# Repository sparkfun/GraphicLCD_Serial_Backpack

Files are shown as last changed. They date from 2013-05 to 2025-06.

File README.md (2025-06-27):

Graphic LCD Serial Backpack
============================
[Graphic LCD Serial Backpack
*Graphic LCD Serial Backpack(LCD-09352)*](https://www.sparkfun.com/products/9352)

The Graphic LCD Serial Backpack interfaces to either the [160x128 pixel Huge Graphic LCD](https://www.sparkfun.com/products/8799) or
the [128x64 pixel display](https://www.sparkfun.com/products/710). The backpack will allow you to write text, draw lines, circles and boxes, 
set and reset individual pixels, and erase specific blocks of the display. 

Repository Contents
-------------------
* **/Firmware** - The firmware that comes installed on the backpack
* **/Hardware** - All Eagle design files (.brd, .sch)

Product Versions
----------------
* [LCD-09352](https://www.sparkfun.com/products/9352)- Graphic Serial LCD Backpack by itself
* [LCD-09351](https://www.sparkfun.com/products/9351) - Serial Graphic LCD 128x64 (LCD + backpack)
* [LCD-08884](https://www.sparkfun.com/products/8884) - Serial Graphic LCD 160x128 (LCD + backpack)

License Information
-------------------
The hardware is released under [Creative Commons Share-alike 3.0](http://creativecommons.org/licenses/by-sa/3.0/).  
All other code is open source so please feel free to do anything you want with it; you buy me a beer if you use this and we meet someday ([Beerware license](http://en.wikipedia.org/wiki/Beerware)).

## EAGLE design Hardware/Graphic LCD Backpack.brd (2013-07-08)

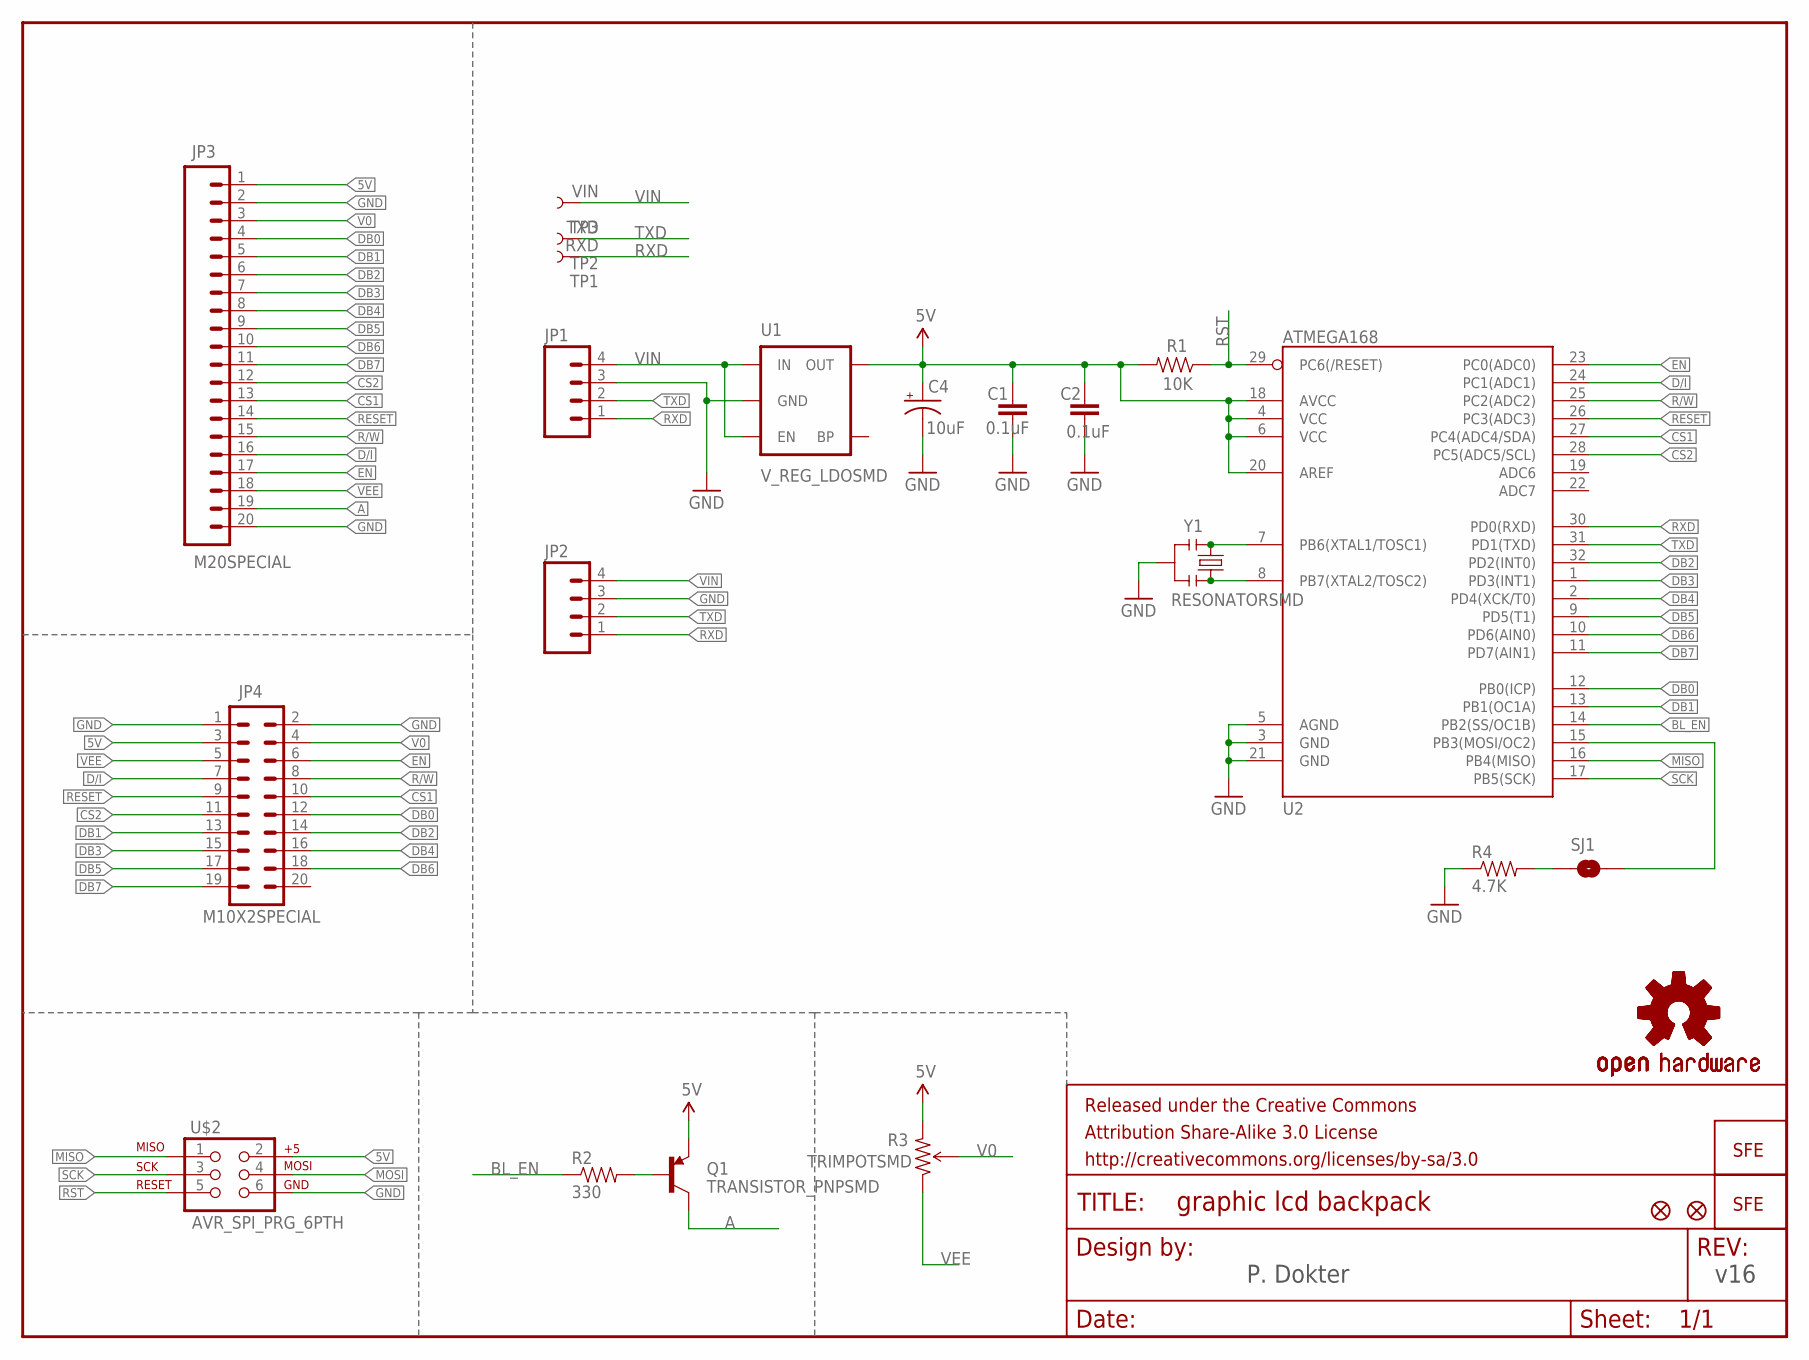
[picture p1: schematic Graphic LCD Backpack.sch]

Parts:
C1, C2: 0.1uF; 0603-CAP
C4: 10uF; EIA3216
FRAME1: FRAME-LETTER; CREATIVE_COMMONS
JP1: M04SMD; 1X04-SMD
JP2: M04PTH; 1X04
JP3: M20SPECIAL; 1X20_LOCK_SPECIAL
JP4: M10X2SPECIAL; 2X10_LOCK_SPECIAL
LOGO1: OSHW-LOGOL; OSHW-LOGO-L
LOGO2: LOGO-SFENEW; SFE-NEW-WEBLOGO
LOGO3: OSHW-LOGOS; OSHW-LOGO-S
Q1: TRANSISTOR_PNPSMD; SOT23-3
R1: 10K; 0603-RES
R2: 330; 0603-RES
R3: TRIMPOTSMD; TRIMPOT-3MM
R4: 4.7K; 0603-RES
SJ1: SOLDERJUMPERNC2; SJ_2S-NOTRACE
TP1: RXD; PAD.03X.05
TP2: TXD; PAD.03X.05
TP3: VIN; PAD.03X.05
U1: V_REG_LDOSMD; SOT23-5
U2: ATMEGA168; TQFP32-08
U$2: AVR_SPI_PRG_6PTH; 2X3
U$8: LOGO-SFENEW; SFE-NEW-WEBLOGO
U$9, U$10: FIDUCIAL1X2; FIDUCIAL-1X2
Y1: RESONATORSMD; RESONATOR-SMD

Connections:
5V: C1.1, C2.2, C4.A (+), JP3.1, JP4.3, Q1.2 (E), R1.2, R3.3 (CW), U1.5 (OUT), U2.4 (VCC), U2.6 (VCC), U2.18 (AVCC), U2.20 (AREF), U$2.2
A: JP3.19, Q1.3 (C)
BL_EN: R2.1, U2.14 (PB2(SS/OC1B))
CS1: JP3.13, JP4.10, U2.27 (PC4(ADC4/SDA))
CS2: JP3.12, JP4.11, U2.28 (PC5(ADC5/SCL))
D/I: JP3.16, JP4.7, U2.24 (PC1(ADC1))
DB0: JP3.4, JP4.12, U2.12 (PB0(ICP))
DB1: JP3.5, JP4.13, U2.13 (PB1(OC1A))
DB2: JP3.6, JP4.14, U2.32 (PD2(INT0))
DB3: JP3.7, JP4.15, U2.1 (PD3(INT1))
DB4: JP3.8, JP4.16, U2.2 (PD4(XCK/T0))
DB5: JP3.9, JP4.17, U2.9 (PD5(T1))
DB6: JP3.10, JP4.18, U2.10 (PD6(AIN0))
DB7: JP3.11, JP4.19, U2.11 (PD7(AIN1))
EN: JP3.17, JP4.6, U2.23 (PC0(ADC0))
GND: C1.2, C2.1, C4.C (-), JP1.3, JP2.3, JP3.2, JP3.20, JP4.1, JP4.2, R4.1, U1.2 (GND), U2.3 (GND), U2.5 (AGND), U2.21 (GND), U$2.6, Y1.2
MISO: U2.16 (PB4(MISO)), U$2.1
MOSI: SJ1.2, U2.15 (PB3(MOSI/OC2)), U$2.4
unnamed: Q1.1 (B), R2.2
unnamed: U2.7 (PB6(XTAL1/TOSC1)), Y1.1
unnamed: U2.8 (PB7(XTAL2/TOSC2)), Y1.3
unnamed: R4.2, SJ1.1
R/W: JP3.15, JP4.8, U2.25 (PC2(ADC2))
RESET: JP3.14, JP4.9, U2.26 (PC3(ADC3))
RST: R1.1, U2.29 (PC6(/RESET)), U$2.5
RXD: JP1.1, JP2.1, TP1.P$1, U2.30 (PD0(RXD))
SCK: U2.17 (PB5(SCK)), U$2.3
TXD: JP1.2, JP2.2, TP2.P$1, U2.31 (PD1(TXD))
V0: JP3.3, JP4.4, R3.2 (WIPER)
VEE: JP3.18, JP4.5, R3.1 (CCW)
VIN: JP1.4, JP2.4, TP3.P$1, U1.1 (IN), U1.3 (EN)

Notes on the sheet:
v16
P. Dokter

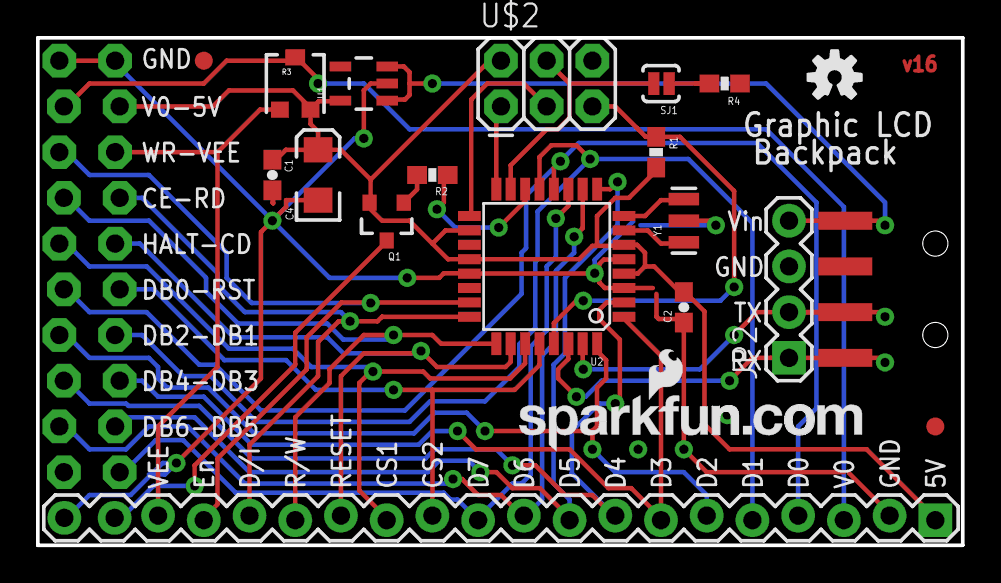
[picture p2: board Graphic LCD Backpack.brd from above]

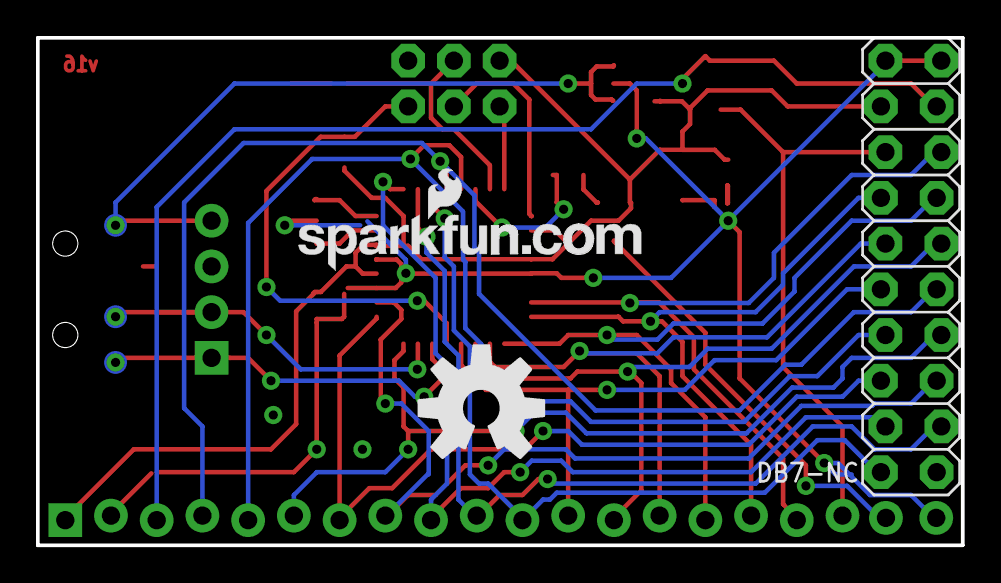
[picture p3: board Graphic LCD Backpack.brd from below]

Board: 2 copper layers, 51.4 x 28.2 mm, 27 parts (6 on the bottom side), 31 nets.

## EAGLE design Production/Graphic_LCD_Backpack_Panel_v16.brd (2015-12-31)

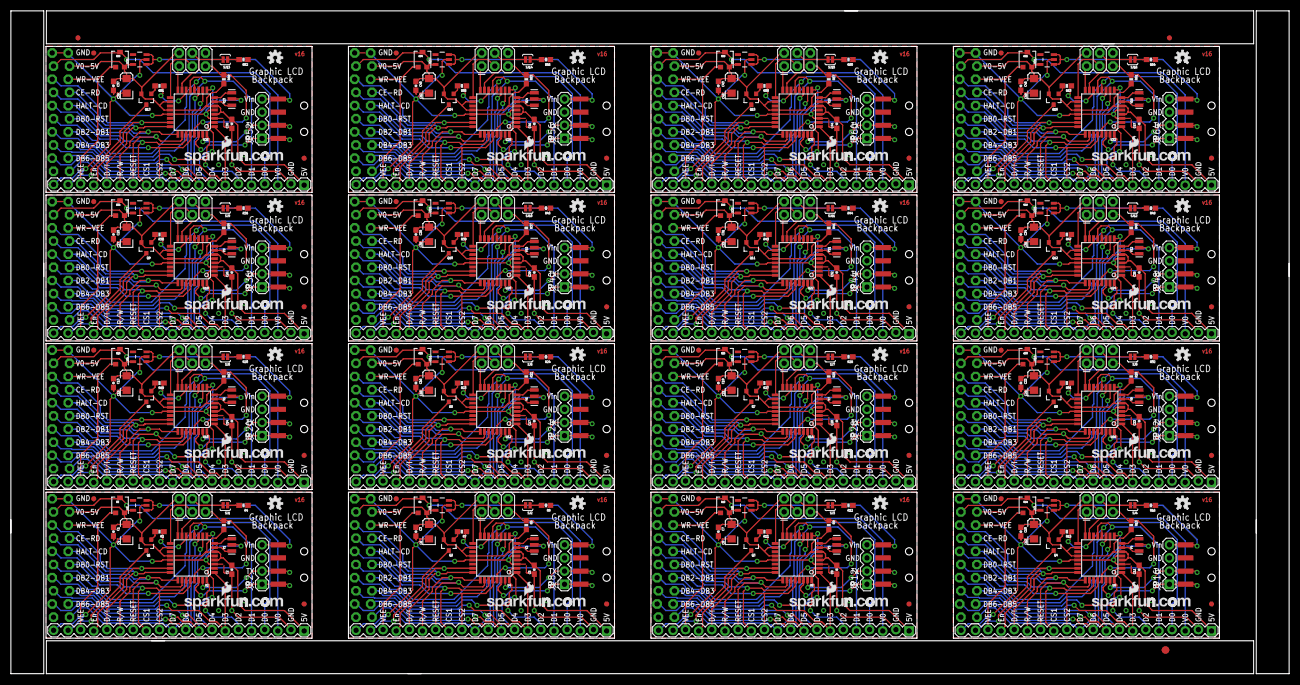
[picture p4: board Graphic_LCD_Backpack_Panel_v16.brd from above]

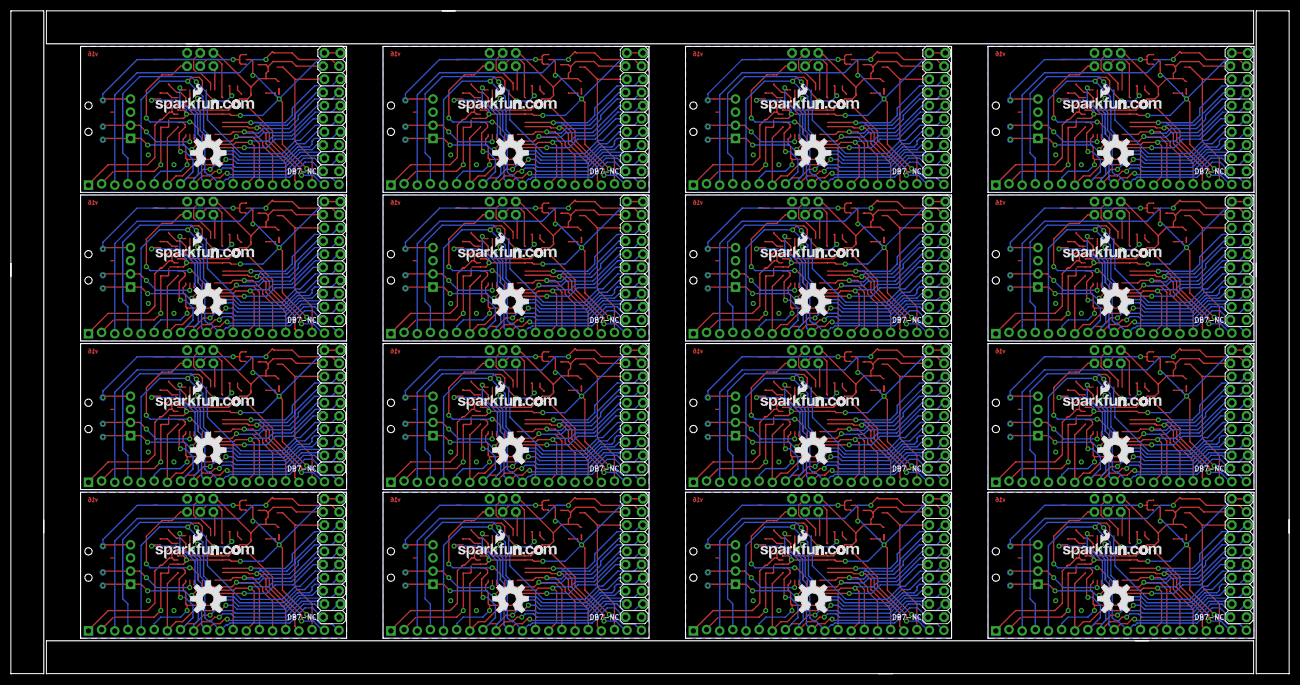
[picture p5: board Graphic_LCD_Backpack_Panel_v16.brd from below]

Board: 2 copper layers, 246.9 x 128.0 mm, 419 parts (96 on the bottom side), 496 nets.

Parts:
C1, C2, C3, C5, C7, C8, C10, C11, C13, C14, C16, C17, C19, C20, C22, C23, C25, C26, C28, C29, C31, C32, C34, C35, C37, C38, C40, C41, C43, C44, C46, C47: 0.1uF; 0603-CAP
C4, C6, C9, C12, C15, C18, C21, C24, C27, C30, C33, C36, C39, C42, C45, C48: 10uF; EIA3216
E$1: FIDUCIAL-1.5X3
E$7, E$8: FIDUCIAL-1X2
JP1, JP7, JP11, JP15, JP19, JP23, JP27, JP31, JP35, JP39, JP43, JP47, JP51, JP55, JP59, JP63: 1X04-SMD
JP2, JP8, JP12, JP16, JP20, JP24, JP28, JP32, JP36, JP40, JP44, JP48, JP52, JP56, JP60, JP64: 1X04
JP3, JP5, JP9, JP13, JP17, JP21, JP25, JP29, JP33, JP37, JP41, JP45, JP49, JP53, JP57, JP61: M20SPECIAL; 1X20_LOCK_SPECIAL
JP4, JP6, JP10, JP14, JP18, JP22, JP26, JP30, JP34, JP38, JP42, JP46, JP50, JP54, JP58, JP62: M10X2SPECIAL; 2X10_LOCK_SPECIAL
LOGO1, LOGO4, LOGO7, LOGO10, LOGO13, LOGO16, LOGO19, LOGO22, LOGO25, LOGO28, LOGO31, LOGO34, LOGO37, LOGO40, LOGO43, LOGO46: OSHW-LOGOL; OSHW-LOGO-L
LOGO2, LOGO5, LOGO8, LOGO11, LOGO14, LOGO17, LOGO20, LOGO23, LOGO26, LOGO29, LOGO32, LOGO35, LOGO38, LOGO41, LOGO44, LOGO47: LOGO-SFENEW; SFE-NEW-WEBLOGO
LOGO3, LOGO6, LOGO9, LOGO12, LOGO15, LOGO18, LOGO21, LOGO24, LOGO27, LOGO30, LOGO33, LOGO36, LOGO39, LOGO42, LOGO45, LOGO48: OSHW-LOGOS; OSHW-LOGO-S
Q1, Q2, Q3, Q4, Q5, Q6, Q7, Q8, Q9, Q10, Q11, Q12, Q13, Q14, Q15, Q16: TRANSISTOR_PNPSMD; SOT23-3
R1, R5, R9, R13, R17, R21, R25, R29, R33, R37, R41, R45, R49, R53, R57, R61: 10K; 0603-RES
R2, R7, R11, R15, R19, R23, R27, R31, R35, R39, R43, R47, R51, R55, R59, R63: 330; 0603-RES
R3, R6, R10, R14, R18, R22, R26, R30, R34, R38, R42, R46, R50, R54, R58, R62: TRIMPOTSMD; TRIMPOT-3MM
R4, R8, R12, R16, R20, R24, R28, R32, R36, R40, R44, R48, R52, R56, R60, R64: 4.7K; 0603-RES
SJ1, SJ2, SJ3, SJ4, SJ5, SJ6, SJ7, SJ8, SJ9, SJ10, SJ11, SJ12, SJ13, SJ14, SJ15, SJ16: SOLDERJUMPERNC2; SJ_2S-NOTRACE
TP1, TP4, TP7, TP10, TP13, TP16, TP19, TP22, TP25, TP28, TP31, TP34, TP37, TP40, TP43, TP46: RXD; PAD.03X.05
TP2, TP5, TP8, TP11, TP14, TP17, TP20, TP23, TP26, TP29, TP32, TP35, TP38, TP41, TP44, TP47: TXD; PAD.03X.05
TP3, TP6, TP9, TP12, TP15, TP18, TP21, TP24, TP27, TP30, TP33, TP36, TP39, TP42, TP45, TP48: VIN; PAD.03X.05
U1, U3, U5, U7, U9, U11, U13, U15, U17, U19, U21, U23, U25, U27, U29, U31: V_REG_LDOSMD; SOT23-5
U2, U4, U6, U8, U10, U12, U14, U16, U18, U20, U22, U24, U26, U28, U30, U32: ATMEGA168; TQFP32-08
U$1, U$6, U$8, U$13, U$17, U$21, U$25, U$29, U$33, U$37, U$41, U$45, U$49, U$53, U$57, U$61: LOGO-SFENEW; SFE-NEW-WEBLOGO
U$2, U$5, U$12, U$16, U$20, U$24, U$28, U$32, U$36, U$40, U$44, U$48, U$52, U$56, U$60, U$64: AVR_SPI_PRG_6PTH; 2X3
U$3, U$4, U$7, U$9, U$10, U$11, U$14, U$15, U$18, U$19, U$22, U$23, U$26, U$27, U$30, U$31, U$34, U$35, U$38, U$39, U$42, U$43, U$46, U$47, U$50, U$51, U$54, U$55, U$58, U$59, U$62, U$63: FIDUCIAL1X2; FIDUCIAL-1X2
Y1, Y2, Y3, Y4, Y5, Y6, Y7, Y8, Y9, Y10, Y11, Y12, Y13, Y14, Y15, Y16: RESONATORSMD; RESONATOR-SMD

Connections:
5V: C1.1, C2.2, C4.A, JP3.1, JP4.3, Q1.2, R1.2, R3.3, U1.5, U2.4, U2.6, U2.18, U2.20, U$2.2
5V1: C3.1, C5.2, C6.A, JP5.1, JP6.3, Q2.2, R5.2, R6.3, U3.5, U4.4, U4.6, U4.18, U4.20, U$5.2
5V2: C7.1, C8.2, C9.A, JP9.1, JP10.3, Q3.2, R9.2, R10.3, U5.5, U6.4, U6.6, U6.18, U6.20, U$12.2
5V3: C10.1, C11.2, C12.A, JP13.1, JP14.3, Q4.2, R13.2, R14.3, U7.5, U8.4, U8.6, U8.18, U8.20, U$16.2
5V4: C13.1, C14.2, C15.A, JP17.1, JP18.3, Q5.2, R17.2, R18.3, U9.5, U10.4, U10.6, U10.18, U10.20, U$20.2
5V5: C16.1, C17.2, C18.A, JP21.1, JP22.3, Q6.2, R21.2, R22.3, U11.5, U12.4, U12.6, U12.18, U12.20, U$24.2
5V6: C19.1, C20.2, C21.A, JP25.1, JP26.3, Q7.2, R25.2, R26.3, U13.5, U14.4, U14.6, U14.18, U14.20, U$28.2
5V7: C22.1, C23.2, C24.A, JP29.1, JP30.3, Q8.2, R29.2, R30.3, U15.5, U16.4, U16.6, U16.18, U16.20, U$32.2
5V8: C25.1, C26.2, C27.A, JP33.1, JP34.3, Q9.2, R33.2, R34.3, U17.5, U18.4, U18.6, U18.18, U18.20, U$36.2
5V9: C28.1, C29.2, C30.A, JP37.1, JP38.3, Q10.2, R37.2, R38.3, U19.5, U20.4, U20.6, U20.18, U20.20, U$40.2
5V10: C31.1, C32.2, C33.A, JP41.1, JP42.3, Q11.2, R41.2, R42.3, U21.5, U22.4, U22.6, U22.18, U22.20, U$44.2
5V11: C34.1, C35.2, C36.A, JP45.1, JP46.3, Q12.2, R45.2, R46.3, U23.5, U24.4, U24.6, U24.18, U24.20, U$48.2
5V12: C37.1, C38.2, C39.A, JP49.1, JP50.3, Q13.2, R49.2, R50.3, U25.5, U26.4, U26.6, U26.18, U26.20, U$52.2
5V13: C40.1, C41.2, C42.A, JP53.1, JP54.3, Q14.2, R53.2, R54.3, U27.5, U28.4, U28.6, U28.18, U28.20, U$56.2
5V14: C43.1, C44.2, C45.A, JP57.1, JP58.3, Q15.2, R57.2, R58.3, U29.5, U30.4, U30.6, U30.18, U30.20, U$60.2
5V15: C46.1, C47.2, C48.A, JP61.1, JP62.3, Q16.2, R61.2, R62.3, U31.5, U32.4, U32.6, U32.18, U32.20, U$64.2
A: JP3.19, Q1.3
A1: JP5.19, Q2.3
A2: JP9.19, Q3.3
A3: JP13.19, Q4.3
A4: JP17.19, Q5.3
A5: JP21.19, Q6.3
A6: JP25.19, Q7.3
A7: JP29.19, Q8.3
A8: JP33.19, Q9.3
A9: JP37.19, Q10.3
A10: JP41.19, Q11.3
A11: JP45.19, Q12.3
A12: JP49.19, Q13.3
A13: JP53.19, Q14.3
A14: JP57.19, Q15.3
A15: JP61.19, Q16.3
BL_EN: R2.1, U2.14
BL_EN1: R7.1, U4.14
BL_EN2: R11.1, U6.14
BL_EN3: R15.1, U8.14
BL_EN4: R19.1, U10.14
BL_EN5: R23.1, U12.14
BL_EN6: R27.1, U14.14
BL_EN7: R31.1, U16.14
BL_EN8: R35.1, U18.14
BL_EN9: R39.1, U20.14
BL_EN10: R43.1, U22.14
BL_EN11: R47.1, U24.14
BL_EN12: R51.1, U26.14
BL_EN13: R55.1, U28.14
BL_EN14: R59.1, U30.14
BL_EN15: R63.1, U32.14
CS1: JP3.13, JP4.10, U2.27
CS2: JP3.12, JP4.11, U2.28
CS3: JP5.12, JP6.11, U4.28
CS4: JP5.13, JP6.10, U4.27
CS5: JP9.12, JP10.11, U6.28
CS6: JP9.13, JP10.10, U6.27
CS7: JP13.12, JP14.11, U8.28
CS8: JP13.13, JP14.10, U8.27
CS9: JP17.12, JP18.11, U10.28
CS10: JP17.13, JP18.10, U10.27
CS11: JP21.12, JP22.11, U12.28
CS12: JP21.13, JP22.10, U12.27
CS13: JP25.12, JP26.11, U14.28
CS14: JP25.13, JP26.10, U14.27
CS15: JP29.12, JP30.11, U16.28
CS16: JP29.13, JP30.10, U16.27
CS17: JP33.12, JP34.11, U18.28
CS18: JP33.13, JP34.10, U18.27
CS19: JP37.12, JP38.11, U20.28
CS20: JP37.13, JP38.10, U20.27
CS21: JP41.12, JP42.11, U22.28
CS22: JP41.13, JP42.10, U22.27
CS23: JP45.12, JP46.11, U24.28
CS24: JP45.13, JP46.10, U24.27
CS25: JP49.12, JP50.11, U26.28
CS26: JP49.13, JP50.10, U26.27
CS27: JP53.12, JP54.11, U28.28
CS28: JP53.13, JP54.10, U28.27
CS29: JP57.12, JP58.11, U30.28
CS30: JP57.13, JP58.10, U30.27
CS31: JP61.12, JP62.11, U32.28
CS32: JP61.13, JP62.10, U32.27
D/I: JP3.16, JP4.7, U2.24
D/I1: JP5.16, JP6.7, U4.24
D/I2: JP9.16, JP10.7, U6.24
D/I3: JP13.16, JP14.7, U8.24
D/I4: JP17.16, JP18.7, U10.24
D/I5: JP21.16, JP22.7, U12.24
D/I6: JP25.16, JP26.7, U14.24
D/I7: JP29.16, JP30.7, U16.24
D/I8: JP33.16, JP34.7, U18.24
D/I9: JP37.16, JP38.7, U20.24
D/I10: JP41.16, JP42.7, U22.24
D/I11: JP45.16, JP46.7, U24.24
D/I12: JP49.16, JP50.7, U26.24
D/I13: JP53.16, JP54.7, U28.24
D/I14: JP57.16, JP58.7, U30.24
D/I15: JP61.16, JP62.7, U32.24
DB0: JP3.4, JP4.12, U2.12
DB1: JP3.5, JP4.13, U2.13
DB2: JP3.6, JP4.14, U2.32
DB3: JP3.7, JP4.15, U2.1
DB4: JP3.8, JP4.16, U2.2
DB5: JP3.9, JP4.17, U2.9
DB6: JP3.10, JP4.18, U2.10
DB7: JP3.11, JP4.19, U2.11
DB8: JP5.4, JP6.12, U4.12
DB9: JP5.5, JP6.13, U4.13
DB10: JP5.6, JP6.14, U4.32
DB11: JP5.7, JP6.15, U4.1
DB12: JP5.8, JP6.16, U4.2
DB13: JP5.9, JP6.17, U4.9
DB14: JP5.10, JP6.18, U4.10
DB15: JP5.11, JP6.19, U4.11
DB16: JP9.4, JP10.12, U6.12
DB17: JP9.5, JP10.13, U6.13
DB18: JP9.6, JP10.14, U6.32
DB19: JP9.7, JP10.15, U6.1
DB20: JP9.8, JP10.16, U6.2
DB21: JP9.9, JP10.17, U6.9
DB22: JP9.10, JP10.18, U6.10
DB23: JP9.11, JP10.19, U6.11
DB24: JP13.4, JP14.12, U8.12
DB25: JP13.5, JP14.13, U8.13
DB26: JP13.6, JP14.14, U8.32
DB27: JP13.7, JP14.15, U8.1
DB28: JP13.8, JP14.16, U8.2
DB29: JP13.9, JP14.17, U8.9
DB30: JP13.10, JP14.18, U8.10
DB31: JP13.11, JP14.19, U8.11
DB32: JP17.4, JP18.12, U10.12
DB33: JP17.5, JP18.13, U10.13
DB34: JP17.6, JP18.14, U10.32
DB35: JP17.7, JP18.15, U10.1
DB36: JP17.8, JP18.16, U10.2
DB37: JP17.9, JP18.17, U10.9
DB38: JP17.10, JP18.18, U10.10
DB39: JP17.11, JP18.19, U10.11
DB40: JP21.4, JP22.12, U12.12
DB41: JP21.5, JP22.13, U12.13
DB42: JP21.6, JP22.14, U12.32
DB43: JP21.7, JP22.15, U12.1
DB44: JP21.8, JP22.16, U12.2
DB45: JP21.9, JP22.17, U12.9
DB46: JP21.10, JP22.18, U12.10
DB47: JP21.11, JP22.19, U12.11
DB48: JP25.4, JP26.12, U14.12
DB49: JP25.5, JP26.13, U14.13
DB50: JP25.6, JP26.14, U14.32
DB51: JP25.7, JP26.15, U14.1
DB52: JP25.8, JP26.16, U14.2
DB53: JP25.9, JP26.17, U14.9
DB54: JP25.10, JP26.18, U14.10
DB55: JP25.11, JP26.19, U14.11
DB56: JP29.4, JP30.12, U16.12
DB57: JP29.5, JP30.13, U16.13
DB58: JP29.6, JP30.14, U16.32
DB59: JP29.7, JP30.15, U16.1
DB60: JP29.8, JP30.16, U16.2
DB61: JP29.9, JP30.17, U16.9
DB62: JP29.10, JP30.18, U16.10
DB63: JP29.11, JP30.19, U16.11
DB64: JP33.4, JP34.12, U18.12
DB65: JP33.5, JP34.13, U18.13
DB66: JP33.6, JP34.14, U18.32
DB67: JP33.7, JP34.15, U18.1
DB68: JP33.8, JP34.16, U18.2
DB69: JP33.9, JP34.17, U18.9
DB70: JP33.10, JP34.18, U18.10
DB71: JP33.11, JP34.19, U18.11
DB72: JP37.4, JP38.12, U20.12
DB73: JP37.5, JP38.13, U20.13
DB74: JP37.6, JP38.14, U20.32
DB75: JP37.7, JP38.15, U20.1
DB76: JP37.8, JP38.16, U20.2
DB77: JP37.9, JP38.17, U20.9
DB78: JP37.10, JP38.18, U20.10
DB79: JP37.11, JP38.19, U20.11
DB80: JP41.4, JP42.12, U22.12
DB81: JP41.5, JP42.13, U22.13
DB82: JP41.6, JP42.14, U22.32
DB83: JP41.7, JP42.15, U22.1
DB84: JP41.8, JP42.16, U22.2
DB85: JP41.9, JP42.17, U22.9
DB86: JP41.10, JP42.18, U22.10
DB87: JP41.11, JP42.19, U22.11
DB88: JP45.4, JP46.12, U24.12
DB89: JP45.5, JP46.13, U24.13
DB90: JP45.6, JP46.14, U24.32
DB91: JP45.7, JP46.15, U24.1
DB92: JP45.8, JP46.16, U24.2
DB93: JP45.9, JP46.17, U24.9
DB94: JP45.10, JP46.18, U24.10
DB95: JP45.11, JP46.19, U24.11
DB96: JP49.4, JP50.12, U26.12
DB97: JP49.5, JP50.13, U26.13
DB98: JP49.6, JP50.14, U26.32
DB99: JP49.7, JP50.15, U26.1
DB100: JP49.8, JP50.16, U26.2
DB101: JP49.9, JP50.17, U26.9
DB102: JP49.10, JP50.18, U26.10
DB103: JP49.11, JP50.19, U26.11
DB104: JP53.4, JP54.12, U28.12
DB105: JP53.5, JP54.13, U28.13
DB106: JP53.6, JP54.14, U28.32
DB107: JP53.7, JP54.15, U28.1
DB108: JP53.8, JP54.16, U28.2
DB109: JP53.9, JP54.17, U28.9
DB110: JP53.10, JP54.18, U28.10
DB111: JP53.11, JP54.19, U28.11
DB112: JP57.4, JP58.12, U30.12
DB113: JP57.5, JP58.13, U30.13
DB114: JP57.6, JP58.14, U30.32
DB115: JP57.7, JP58.15, U30.1
DB116: JP57.8, JP58.16, U30.2
DB117: JP57.9, JP58.17, U30.9
DB118: JP57.10, JP58.18, U30.10
DB119: JP57.11, JP58.19, U30.11
DB120: JP61.4, JP62.12, U32.12
DB121: JP61.5, JP62.13, U32.13
DB122: JP61.6, JP62.14, U32.32
DB123: JP61.7, JP62.15, U32.1
DB124: JP61.8, JP62.16, U32.2
DB125: JP61.9, JP62.17, U32.9
DB126: JP61.10, JP62.18, U32.10
DB127: JP61.11, JP62.19, U32.11
EN: JP3.17, JP4.6, U2.23
EN1: JP5.17, JP6.6, U4.23
EN2: JP9.17, JP10.6, U6.23
EN3: JP13.17, JP14.6, U8.23
EN4: JP17.17, JP18.6, U10.23
EN5: JP21.17, JP22.6, U12.23
EN6: JP25.17, JP26.6, U14.23
EN7: JP29.17, JP30.6, U16.23
EN8: JP33.17, JP34.6, U18.23
EN9: JP37.17, JP38.6, U20.23
EN10: JP41.17, JP42.6, U22.23
EN11: JP45.17, JP46.6, U24.23
EN12: JP49.17, JP50.6, U26.23
EN13: JP53.17, JP54.6, U28.23
EN14: JP57.17, JP58.6, U30.23
EN15: JP61.17, JP62.6, U32.23
GND: C1.2, C2.1, C4.C, JP1.3, JP2.3, JP3.2, JP3.20, JP4.1, JP4.2, R4.1, U1.2, U2.3, U2.5, U2.21, U$2.6, Y1.2
GND1: C3.2, C5.1, C6.C, JP5.2, JP5.20, JP6.1, JP6.2, JP7.3, JP8.3, R8.1, U3.2, U4.3, U4.5, U4.21, U$5.6, Y2.2
GND2: C7.2, C8.1, C9.C, JP9.2, JP9.20, JP10.1, JP10.2, JP11.3, JP12.3, R12.1, U5.2, U6.3, U6.5, U6.21, U$12.6, Y3.2
GND3: C10.2, C11.1, C12.C, JP13.2, JP13.20, JP14.1, JP14.2, JP15.3, JP16.3, R16.1, U7.2, U8.3, U8.5, U8.21, U$16.6, Y4.2
GND4: C13.2, C14.1, C15.C, JP17.2, JP17.20, JP18.1, JP18.2, JP19.3, JP20.3, R20.1, U9.2, U10.3, U10.5, U10.21, U$20.6, Y5.2
GND5: C16.2, C17.1, C18.C, JP21.2, JP21.20, JP22.1, JP22.2, JP23.3, JP24.3, R24.1, U11.2, U12.3, U12.5, U12.21, U$24.6, Y6.2
GND6: C19.2, C20.1, C21.C, JP25.2, JP25.20, JP26.1, JP26.2, JP27.3, JP28.3, R28.1, U13.2, U14.3, U14.5, U14.21, U$28.6, Y7.2
GND7: C22.2, C23.1, C24.C, JP29.2, JP29.20, JP30.1, JP30.2, JP31.3, JP32.3, R32.1, U15.2, U16.3, U16.5, U16.21, U$32.6, Y8.2
GND8: C25.2, C26.1, C27.C, JP33.2, JP33.20, JP34.1, JP34.2, JP35.3, JP36.3, R36.1, U17.2, U18.3, U18.5, U18.21, U$36.6, Y9.2
GND9: C28.2, C29.1, C30.C, JP37.2, JP37.20, JP38.1, JP38.2, JP39.3, JP40.3, R40.1, U19.2, U20.3, U20.5, U20.21, U$40.6, Y10.2
GND10: C31.2, C32.1, C33.C, JP41.2, JP41.20, JP42.1, JP42.2, JP43.3, JP44.3, R44.1, U21.2, U22.3, U22.5, U22.21, U$44.6, Y11.2
GND11: C34.2, C35.1, C36.C, JP45.2, JP45.20, JP46.1, JP46.2, JP47.3, JP48.3, R48.1, U23.2, U24.3, U24.5, U24.21, U$48.6, Y12.2
GND12: C37.2, C38.1, C39.C, JP49.2, JP49.20, JP50.1, JP50.2, JP51.3, JP52.3, R52.1, U25.2, U26.3, U26.5, U26.21, U$52.6, Y13.2
GND13: C40.2, C41.1, C42.C, JP53.2, JP53.20, JP54.1, JP54.2, JP55.3, JP56.3, R56.1, U27.2, U28.3, U28.5, U28.21, U$56.6, Y14.2
GND14: C43.2, C44.1, C45.C, JP57.2, JP57.20, JP58.1, JP58.2, JP59.3, JP60.3, R60.1, U29.2, U30.3, U30.5, U30.21, U$60.6, Y15.2
GND15: C46.2, C47.1, C48.C, JP61.2, JP61.20, JP62.1, JP62.2, JP63.3, JP64.3, R64.1, U31.2, U32.3, U32.5, U32.21, U$64.6, Y16.2
MISO: U2.16, U$2.1
MISO1: U4.16, U$5.1
MISO2: U6.16, U$12.1
MISO3: U8.16, U$16.1
MISO4: U10.16, U$20.1
MISO5: U12.16, U$24.1
MISO6: U14.16, U$28.1
MISO7: U16.16, U$32.1
MISO8: U18.16, U$36.1
MISO9: U20.16, U$40.1
MISO10: U22.16, U$44.1
MISO11: U24.16, U$48.1
MISO12: U26.16, U$52.1
MISO13: U28.16, U$56.1
MISO14: U30.16, U$60.1
MISO15: U32.16, U$64.1
MOSI: SJ1.2, U2.15, U$2.4
MOSI1: SJ2.2, U4.15, U$5.4
MOSI2: SJ3.2, U6.15, U$12.4
MOSI3: SJ4.2, U8.15, U$16.4
MOSI4: SJ5.2, U10.15, U$20.4
MOSI5: SJ6.2, U12.15, U$24.4
MOSI6: SJ7.2, U14.15, U$28.4
MOSI7: SJ8.2, U16.15, U$32.4
MOSI8: SJ9.2, U18.15, U$36.4
MOSI9: SJ10.2, U20.15, U$40.4
MOSI10: SJ11.2, U22.15, U$44.4
MOSI11: SJ12.2, U24.15, U$48.4
MOSI12: SJ13.2, U26.15, U$52.4
MOSI13: SJ14.2, U28.15, U$56.4
MOSI14: SJ15.2, U30.15, U$60.4
MOSI15: SJ16.2, U32.15, U$64.4
unnamed: Q1.1, R2.2
unnamed: U2.7, Y1.1
unnamed: U2.8, Y1.3
unnamed: R4.2, SJ1.1
unnamed: Q2.1, R7.2
unnamed: U4.7, Y2.1
unnamed: U4.8, Y2.3
unnamed: R8.2, SJ2.1
unnamed: Q3.1, R11.2
unnamed: U6.7, Y3.1
unnamed: U6.8, Y3.3
unnamed: R12.2, SJ3.1
unnamed: Q4.1, R15.2
unnamed: U8.7, Y4.1
unnamed: U8.8, Y4.3
unnamed: R16.2, SJ4.1
unnamed: Q5.1, R19.2
unnamed: U10.7, Y5.1
unnamed: U10.8, Y5.3
unnamed: R20.2, SJ5.1
unnamed: Q6.1, R23.2
unnamed: U12.7, Y6.1
unnamed: U12.8, Y6.3
unnamed: R24.2, SJ6.1
unnamed: Q7.1, R27.2
unnamed: U14.7, Y7.1
unnamed: U14.8, Y7.3
unnamed: R28.2, SJ7.1
unnamed: Q8.1, R31.2
unnamed: U16.7, Y8.1
unnamed: U16.8, Y8.3
unnamed: R32.2, SJ8.1
unnamed: Q9.1, R35.2
unnamed: U18.7, Y9.1
unnamed: U18.8, Y9.3
unnamed: R36.2, SJ9.1
unnamed: Q10.1, R39.2
unnamed: U20.7, Y10.1
unnamed: U20.8, Y10.3
unnamed: R40.2, SJ10.1
unnamed: Q11.1, R43.2
unnamed: U22.7, Y11.1
unnamed: U22.8, Y11.3
unnamed: R44.2, SJ11.1
unnamed: Q12.1, R47.2
unnamed: U24.7, Y12.1
unnamed: U24.8, Y12.3
unnamed: R48.2, SJ12.1
unnamed: Q13.1, R51.2
unnamed: U26.7, Y13.1
unnamed: U26.8, Y13.3
unnamed: R52.2, SJ13.1
unnamed: Q14.1, R55.2
unnamed: U28.7, Y14.1
unnamed: U28.8, Y14.3
unnamed: R56.2, SJ14.1
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

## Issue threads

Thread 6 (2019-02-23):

Broke poti

TheGreyDiamond, 2019-02-23:
Hi,
I have a problem. The trimpot of my LCD Backpack broke. The display is showing nothing. Is there any way I can fix that?

nseidle, 2019-03-04:
Bummer! You could try replacing the SMD pot - it's a fairly common SMD 10k pot - part# [TC33X-103ETR-ND](https://www.digikey.com/product-detail/en/bourns-inc/TC33X-2-103E/TC33X-103ECT-ND/612911).

There might also be some ways to solder a permanent SMD resistor there but I'd recommend replacing with a trimpot. It's nearly impossible to pin down a single good contrast resistor value.

TheGreyDiamond, 2019-03-05:
Okay, thanks!

Closed 2019-03-04.

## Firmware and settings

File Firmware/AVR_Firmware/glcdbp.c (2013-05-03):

/***************************************************************************
glcdbp.c

Main application file for the serial graphical LCD backpack project. This is
 the main application loop, as well as the calling function for all init
 code found elsewhere. The PWM timer init code is here, too, because I wasn't
 sure where else to put.

02 May 2013 - Mike Hord, SparkFun Electronics

This code is released under the Creative Commons Attribution Share-Alike 3.0
 license. You are free to reuse, remix, or redistribute it as you see fit,
 so long as you provide attribution to SparkFun Electronics.

***************************************************************************/

#include <avr/interrupt.h>
#include <util/delay.h>
#include "glcdbp.h"
#include "io_support.h"
#include "serial.h"
#include "lcd.h"
#include "ui.h"
#include "nvm.h"

// These variables will be used over and over, in various files, to access
//  global variables that may be needed to make decisions elsewhere.
enum DISPLAY_TYPE   display = SMALL;
volatile uint8_t    rxRingBuffer[BUF_DEPTH];
volatile uint8_t    bufferSize = 0;
volatile uint16_t   rxRingHead = 0;
volatile uint16_t   rxRingTail = 0;
volatile uint8_t    reverse = 0;

int main(void)
{
  // The first thing we want to check is if we have a large or small
  //  display on our hands. We can tell because PB3 will be pulled high if
  //  the display is large (hopefully; that's done at build time).
  PORTB |= 0x08;   // Enable the pull-up on PB3.
  _delay_us(5);    // Wait a few us for the pin to change- this is important!
  uint8_t portTemp = PINB;  // Cache the pins status...
  if ((portTemp & 0x08) == 0x08)  // ...and check to see if what the pin says.
  {
    display = LARGE;  // If the pin is high, call it a large display.
  }
  else 
  {
    display = SMALL;  // If the pin is low, it's a small display.
  }
  PORTB &= ~0x08; // Disable the pull-up on PB3.
  
  // ioInit() configures the IO pins as we'll need them for the rest of the
  //  code; once we've identified our display size, we'll do the pins
  //  accordingly.
  ioInit();
  
  // We use a timer (timer1) for our PWM of the backlight. This function sets
  //  that up as needed.
  timerInit();
  
  // By default, we want to start up at 115200BPS. In a second, we'll check
  //  for any input from the user to see if we should remain at 115200 or
  //  check the EEPROM for a different speed.
  serialInit(BR115200);
  
  // Enable interrupts. The only thing we use interrupts for is serial data.
  sei();
  
  // Check to see if we want to be in white-on-black mode (1) or black-on-white
  //   mode (reverse = 0).
  reverse = 0x01 & getReverse();
  
  // Configure the LCD as it should be configured; we leave this until late
  //  in the process more as a relic of development than anything else, b/c
  //  it was useful to have the other stuff setup first.
  lcdConfig();
  
  // Clear the screen for good measure. This *may* not be necessary, but for
  //  the large display, it definitely is, as the power-on status of that one
  //  is pure garbage, everywhere.
  lcdClearScreen();
  
  // Draw the splash, if the EEPROM value says we should.
  if ((getSplash() & 0x01)==1) lcdDrawLogo();
  
  // Now wait for one second, for the user to override the stored baud rate
  //  and get back to 115200, if they so desire.
  _delay_ms(1000);
  
  // If the user has send *any* character during the splash time, we should
  //  skip this switch and set our baud rate back to 115200.
  if (bufferSize == 0)
  {
    switch(getBaudRate())
    {
      case '1':
      serialInit(BR4800);
      break;
      case '2':
      serialInit(BR9600);
      break;
      case '3':
      serialInit(BR19200);
      break;
      case '4':
      serialInit(BR38400);
      break;
      case '5':
      serialInit(BR57600);
      break;
      case '6':
      serialInit(BR115200);
      break;
      default:
      break;
    }
  }
  else setBaudRate('6');
  
  // Clear off the splash.
  lcdClearScreen();
  
  // Clear the serial buffer. Any data sent during that initial 1s period is
  //  lost; we don't care because we know that data *should* only be for an
  //  emergency baud rate reset.
  clearBuffer();
  
  // This is a troubleshooting message, to let us know that setup has
  //  completed and the display is ready to rock. It is commented in the
  //  production version of the code but left in place.
  // putLine("Ready to serve!");
  
  // Under normal circumstances, we'll spend *all* our time cycling through
  //  this loop, parsing input from the serial port. The serial data is
  //  buffered by an interrupt, and we'll pop that buffer here (and in ui.c)
  //  and make decisions on what to do with it.
  while(1)
  {
    // If there's *anything* in the buffer, we need to deal with it.
    while (bufferSize > 0)
    {
      // serialBufferPop() pulls data from the top of the FIFO that comprises
      //  our serial port buffer, automatically changing the pointers and
      //  stack size.
      char bufferChar = serialBufferPop();
      // If the character received is the command escape character ('|')...
      if (bufferChar == '|')
      {
        while (bufferSize == 0);    // ...wait for the next character...
        bufferChar = serialBufferPop(); // ...fetch the character..
        uiStateMachine(bufferChar); // ... then see what to do.
        // Note that we won't return from the state machine until the command
        //  specified by the character that sends us there has been completed-
        //  there's no bailing out of that process. Yet.
      }
      // Otherwise, draw the character. lcdDrawChar also handles backspace,
      //   carriage return and new line.
      else if (((bufferChar >= ' ') && (bufferChar <= '~')) ||
               (bufferChar == '\r') ||  // Newline.
               (bufferChar == '\b') )   // Backspace.
        lcdDrawChar(bufferChar);
    }
  }
}

void timerInit(void)
{  
  // Timer1 initialization
  //  We use timer 1 fast PWM mode to dim the backlight on the display.
  //  OC1B (PB2) is connected to a BJT for controlling the backlight; the BJT
  //  is PNP so we want to use inverting mode.
  // PWM frequency is fclk/(N*(1+TOP)), where TOP is, in this case 100,
  //  N = 1, and fclk is 16MHz. Thus, Fpwm ~ 160kHz.
  
  // TCCR1A-  7:6 - Channel A compare output mode
  //                 Set to 00 for normal pin operation
  //          5:4 - Channel B compare output mode
  //                 Set to 01 for inverting PWM output mode
  //          3:2 - Don't care/no use
  //          1:0 - Waveform generation mode bits 1:0
  //                 Along with WGM1 3:2 (In TCCR1B), set to 1111 to enable
  //                 fast PWM mode. TCNT1 will increment until it reaches ICR1,
  //                 then reset, and the pin will change when TCNT1 == 0 and
  //                 when TCNT1 == OCR1B.
  TCCR1A = 0b00110010;
  
  // TCCR1B-  7   - Input noise canceler (Don't care)
  //          6   - Input capture edge select (Don't care)
  //          5   - Don't care/no use
  //          4:3 - Waveform generation mode bits 3:2
  //                 See above; set to 11 for fast PWM
  //          2:0 - Timer 1 clock source
  //                 Set to 001 for no clock divisor.
  TCCR1B = 0b00011001;
  
  // ICR1-  Really implemented as two 8-bit registers (ICR1L and ICR1H),
  //  the value in this register (in this mode) marks the point at which
  //  the timer quits counting and returns to zero. By making it 100, we
  //  can then really easily set our backlight intensity from 0-100.
  ICR1 = 100;
  
  // OCR1B- Really implemented as two 8-bit registers (OCR1BL and OCR1BH),
  //  the value in this register is the point where the output pin will
  //  transition from low to high, turning the backlight off. We have a
  //  value stored in EEPROM, so we need to retrieve it.
  OCR1B = getBacklightLevel();
}

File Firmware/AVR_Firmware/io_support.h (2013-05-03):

/***************************************************************************
io_support.h

Pin definitions and function prototypes for the io_support.c file.

02 May 2013 - Mike Hord, SparkFun Electronics

This code is released under the Creative Commons Attribution Share-Alike 3.0
 license. You are free to reuse, remix, or redistribute it as you see fit,
 so long as you provide attribution to SparkFun Electronics.

***************************************************************************/


#ifndef __io_support_h
#define __io_support_h

// Pinout definitions.

#define nBL_EN 		2	//PB2 is backlight enable, and is active low

// Pins for the ks0108b (128x64) display
#define EN      0	// PC0
#define RS      1	// PC1
#define R_W     2	// PC2
#define RESET   3	// PC3
#define CS1     4	// PC4
#define CS2     5	// PC5

// Pins for the t6963 (160x128) display
#define WR      0	// PC0
#define RD      1	// PC1
#define CE      2	// PC2
#define CD      3	// PC3
#define HALT    4	// PC4
#define RST     5	// PC5

void    ioInit(void);
void    setData(uint8_t data);
uint8_t readData(void);
void    hiZDataPins(void);

#endif

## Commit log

2012-12-14 Initial commit, lots to do. - TX seems to be working okay - Backlight PWM is working okay - Ring buffer and RX stuff is in place but untested - IO code for the t6963 driver is in place but not tested
2012-12-31 Finally got writing to the ks0108b working. Let's commit here, so we have a failsafe, then I'm going to clean it up and start adding control over the second page of the display...
    [glcdbp.c, ks0108b.c]
2013-01-07 Added an io_support file for IO configuration and read/write to the 8-bit non-concomitant data lines. ks0108bReadData doesn't work; trying to sort out why. Added putDec and putLine to serial. Added a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
    [glcdbp.c, io_support.c, io_support.h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]
2013-04-17 Finished work on line and pixel drawing - ks0108bReadData() needed some work - added a putBin() serial function to print binary output
2013-04-17 Added character display mode - added draw column to ks0108b and lcd - added draw character to lcd - added "cursor" tracking function to lcd - fixed character map array so characters display right sid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
    [glcdbp.c, ks0108b.c, lcd.c]
2013-04-18 Begin work on serial UI - Added ui.c and ui.h - Implemented a pop function for serial buffer in serial.c - Add serial ring buffer access to serial.c - Adjust includes on lcd.h and lcd.c - begin to im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
    Command parsing not yet implemented; drawPixel doesn't work yet.
    [glcdbp.c, lcd.c, serial.c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]
2013-04-19 Implement serial draw pixel and line
    - glcdbp.c: clear buffer after command receipt
    - lcd.c: add draw/erase pixel logic to all draw funcs
    - serial.c: fix ring buffer pop logic for end of buffer wrap
    - ui.c: add/fix draw line and pixel commands
    [glcdbp.c, lcd.c, serial.c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]
2013-04-21 Working on backspace, newline support Works on 0,0 origin, at least. - glcdbp.c: * changed the ring buffer depth to a settable constant, set to 256 * added logic to detect a new line or backspace key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
    [glcdbp.c, ks0108b.c, lcd.c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]
2013-04-22 Add command escape character
    - glcdbp.c: add '|' as an escape character to command mode
    - ks0108b.c: fixing some tab/space issues
    - lcd.c: added lcdDrawSprite(), but no functionality yet
    - lcd.h: same
    [glcdbp.c, ks0108b.c, lcd.c]
2013-04-22 Added display size logic - glcdbp.c: * add lots of comments * add check for display size setting pin (PB3) - io_support.c: * add DISPLAY_TYPE enum * add display size check and large screen init code 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
2013-05-02 Large display integration nearly complete. glcdbp.c: - added delay to display discovery section - moved lcdConfig() farther down the execution order - added some whitespace and comments for readabili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
    [glcdbp.c, lcd.c, t6963.c]
2013-05-02 Large screen should be done. glcdbp.c: comments only interrupt.c: comments only ks0108b.c: - remove unused ks0108bBusyWait() function - remove unused ks0108bDisplayOff() function - remove unused ks01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
2013-05-03 Clean up and comments - glcdbp.c: comments only - glcdbp.h: change buffer depth to 32, comments - interrupts.c: comments only - io_support.c: comments only - io_support.h: comments only - ks0108b.c: 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
2013-05-03 Added draw sprite to UI - glcdbp.c: uncomment 1s delay - t6963.c: remove debugging prints from readBlock - ui.c: * draw circle had a bug re: number of characters in command * added draw sprite method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
    [glcdbp.c, t6963.c, ui.c]
2013-05-03 Final cleanup- fixing some bugs, add demo. Chiefly, masking issues for sprites and the infamous 'd' changes the screen brightness on the small display. - Makefile: add demo.c - glcdbp.c: remove boot 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
    [glcdbp.c, io_support.c, io_support.h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]
2013-07-02 Initial Hardware file commit
    [Graphic LCD Backpack.brd, Graphic LCD Backpack.sch]
2013-07-08 Update label placements
    [Graphic LCD Backpack.brd]
2013-07-24 Fixed enable line issues for small LCD
    [ks0108b.c]
2013-09-24 Fixed bug with long lines on lg disp
    [lcd.c, ui.c]
2013-10-29 Adding Arduino Library
2015-04-24 Initial commit.
    [Graphic LCD Backpack.brd, Graphic LCD Backpack.sch]
2015-04-24 Squashed 'Libraries/Arduino/' content from commit 1deb108
    git-subtree-dir: Libraries/Arduino
    git-subtree-split: 1deb1086befaeaecd1500e15612a955c8936a6f0
2015-04-24 Rearraged for new Arduino library format.
2015-04-27 Removing duplicate copies of AVR files in Arduino library
2015-12-31 created panel v16
    [Graphic_LCD_Backpack_Panel_v16.brd]

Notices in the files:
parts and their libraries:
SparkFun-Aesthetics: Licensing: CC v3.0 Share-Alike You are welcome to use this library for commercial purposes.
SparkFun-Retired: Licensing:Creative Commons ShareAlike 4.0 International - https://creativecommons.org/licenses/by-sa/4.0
